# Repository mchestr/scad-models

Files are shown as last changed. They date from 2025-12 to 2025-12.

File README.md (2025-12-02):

# OpenSCAD Models

A collection of parametric 3D models designed in OpenSCAD for 3D printing.

## Projects

| Project | Description |
|---|---|
| [PSU + QuinLED Enclosure](projects/psu-quinled-enclosure/) | Combined enclosure for a 350W PSU and QuinLED-Dig-Quad controller |

## Structure

```
scad-models/
├── projects/           # Individual model projects
│   └── <project-name>/
│       ├── *.scad      # OpenSCAD source files
│       ├── exports/    # Exported STL files
│       └── README.md   # Project documentation
└── README.md
```

## Usage

1. Open any `.scad` file in [OpenSCAD](https://openscad.org/)
2. Use the Customizer panel to adjust parameters
3. Render (F6) and export to STL for printing

## Requirements

- [OpenSCAD](https://openscad.org/) 2019.05 or later (for Customizer support)

## License

See [LICENSE](LICENSE) for details.

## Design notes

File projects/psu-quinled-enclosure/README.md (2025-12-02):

# PSU + QuinLED Enclosure

A combined enclosure for a 350W power supply and QuinLED-Dig-Quad LED controller, designed for LED lighting projects.

## Features

- Side-by-side layout with PSU and QuinLED controller
- Divider wall with U-shaped cable routing slits
- Ventilation slots on sides and honeycomb lid vents
- Sliding lid design (no screws needed)
- Antenna hole for WiFi/Zigbee connectivity
- LED cable slit for wire routing
- Parametric design - all dimensions customizable

## Components

| Component | Dimensions | Mounting |
|---|---|---|
| PSU | 215.9mm x 115mm x 50mm | M4 screws from bottom |
| QuinLED-Dig-Quad | 100mm x 48mm x 25mm | M2.5 standoffs |

## File Structure

| File | Description |
|---|---|
| `config.scad` | Shared parameters and helper modules |
| `body.scad` | Main enclosure body |
| `lid.scad` | Sliding lid with honeycomb vents |
| `grommet.scad` | Strain relief grommet for power cable |
| `assembled.scad` | Combined view of all parts |

## Parts to Print

- `body.scad` - Main enclosure body (240mm x 186mm x 64mm)
- `lid.scad` - Sliding lid, prints rails-up (240mm x 186mm x 4mm)
- `grommet.scad` - Strain relief grommet

## Assembly

1. Print body and lid
2. Mount PSU with M4 screws from bottom (countersunk)
3. Mount QuinLED board on standoffs with M2.5 screws
4. Route power cables through divider U-slits
5. Route LED cables through side slit
6. Install antenna through back hole
7. Insert grommet into power cable hole
8. Slide lid in from right side until it stops

## Customization

Edit `config.scad` to adjust parameters:

- **PSU Dimensions** - Adjust for different power supplies
- **QuinLED Board** - Board dimensions and mounting holes
- **Wire Routing** - Antenna, LED slit, and power hole sizes
- **Ventilation** - Slot dimensions and spacing

## Exports

Pre-exported STL files in `exports/` directory.

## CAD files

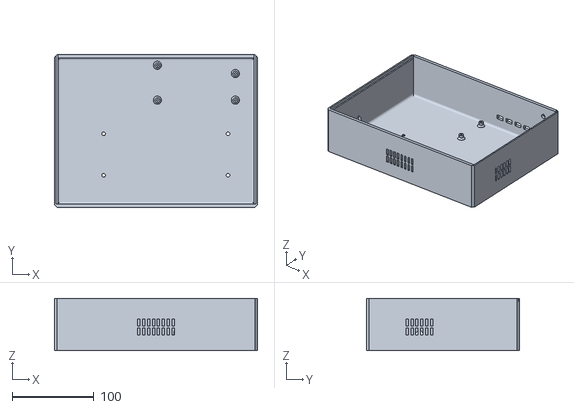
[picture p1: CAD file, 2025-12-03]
projects/psu-quinled-enclosure/exports/body.stl
248.0 x 186.6 x 64.0

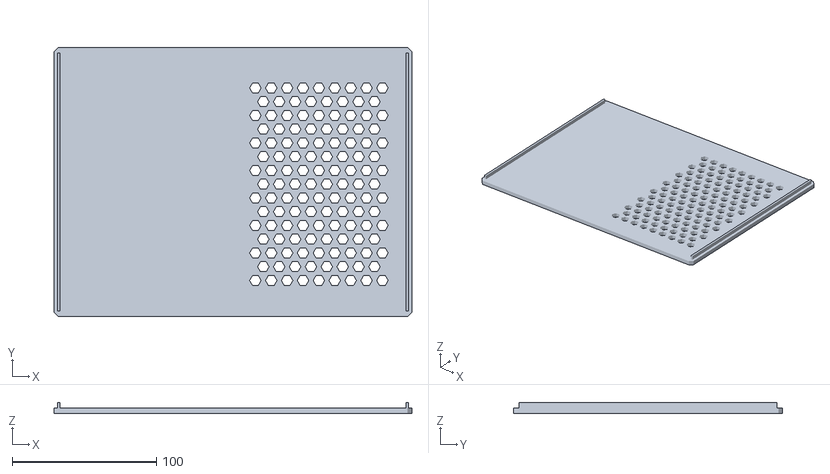
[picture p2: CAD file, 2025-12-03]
projects/psu-quinled-enclosure/exports/lid.stl
248.0 x 186.6 x 7.70

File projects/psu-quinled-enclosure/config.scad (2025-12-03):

// Shared Configuration for PSU + QuinLED Enclosure
// Include this file in other modules to access parameters

/* [Print Compensation] */
// Shrinkage compensation factor (1.0 = none, 1.0135 = ~1.35% for PLA)
// If 150mm prints as 148mm: 150/148 = 1.0135
shrinkage_comp = 1.0135;

/* [PSU Dimensions] */
psu_length = 216;  // 8.5 inches
psu_width = 115;
psu_height = 50;

/* [PSU Mounting Holes] */
psu_hole_spacing_length = 150 * shrinkage_comp;  // Center-to-center distance lengthwise
psu_hole_spacing_width = 50 * shrinkage_comp;    // Center-to-center distance widthwise
psu_screw_dia = 4;  // M4 screws from bottom
psu_screw_head_dia = 8;  // M4 screw head

/* [QuinLED Board] */
quinled_length = 100 * shrinkage_comp;
quinled_width = 48 * shrinkage_comp;
quinled_height = 25;
quinled_hole_edge = 3 * shrinkage_comp;
quinled_hole_offset_back_right = 13 * shrinkage_comp;  // Back-right hole is 13mm from right edge
quinled_hole_dia = 2.5;  // M2.5
quinled_standoff_dia = 6;
quinled_standoff_height = 6;

/* [Enclosure Settings] */
clearance = 3;  // General clearance around components
terminal_clearance = 18;  // Extra space at back for PSU terminal wiring (actual measured offset)
wall = 4;  // Wall thickness
lid_tolerance = 0.3;
chamfer_size = 3;  // Corner chamfer size
internal_fillet_r = 3;  // Internal corner fillet radius for strength

/* [Sliding Lid] */
rail_height = 4;  // Height of the rail/groove
rail_depth = 2;   // How far rail projects into groove
rail_tolerance = 0.3;  // Sliding clearance

/* [Layout] */
gap_between = 3;  // Gap between PSU and QuinLED section
divider_slit_width = 30;  // Slit in divider for power cables
divider_slit_height = 25; // Depth of U-slit from top

/* [Wire Routing] */
antenna_dia = 6;
antenna_offset_from_back = 20;   // Antenna hole distance from back wall
antenna_offset_from_top = 15;    // Antenna hole distance from top
led_slit_width = 80;
led_slit_height = 15;
psu_power_hole_dia = 10;         // PSU AC power cable hole
psu_power_hole_z = 15;           // Height of power cable hole from floor
extra_wire_hole_dia = 10;        // Extra wire routing hole diameter

/* [JST-SM Connectors] */
jst_width = 10;           // Width of JST-SM panel cutout
jst_height = 6;           // Height of JST-SM panel cutout
jst_spacing = 15;         // Spacing between connectors
jst_corner_radius = 1;    // Corner radius for rounded cutouts
jst_count = 4;            // Number of JST connectors

/* [QuinLED Placement] */
quinled_offset_from_back = 20;   // Distance from back wall to QuinLED board

/* [Ventilation] */
slot_width = 3;
slot_length = 20;
slot_spacing = 6;
slot_bridge = 2;      // Bridge between split slots for printability
vent_coverage = 0.8;  // Percentage of lid width covered by honeycomb

/* [Hidden] */
$fn = 60;

// Calculated dimensions
quinled_section_width = quinled_width + clearance * 2;
inner_length = psu_length + clearance * 2 + terminal_clearance;
inner_width = psu_width + clearance * 2 + gap_between + quinled_section_width;
inner_height = psu_height + 10;  // 10mm clearance above PSU for wiring
outer_length = inner_length + wall * 2;
outer_width = inner_width + wall * 2;
outer_height = inner_height + wall;

// Area positions
psu_area_start_x = wall + clearance;
psu_area_start_y = wall + clearance;
psu_area_end_y = psu_area_start_y + psu_width;
quinled_area_start_y = psu_area_end_y + gap_between;
quinled_area_center_y = quinled_area_start_y + quinled_section_width / 2;

// QuinLED board position
quinled_board_x = outer_length - wall - quinled_offset_from_back - quinled_length;
quinled_board_y = quinled_area_start_y + clearance;

// Helper modules
module corner_chamfer(size, height) {
    linear_extrude(height)
        polygon([[0, 0], [size, 0], [0, size]]);
}

module cylinder_fillet(d, fillet_r) {
    rotate_extrude()
        translate([d/2 - fillet_r, 0, 0])
            difference() {
                square([fillet_r + 0.1, fillet_r + 0.1]);
                translate([fillet_r, fillet_r, 0])
                    circle(r=fillet_r);
            }
}

module internal_fillet(length, radius) {
    difference() {
        cube([length, radius, radius]);
        translate([-0.1, radius, radius])
            rotate([0, 90, 0])
                cylinder(r=radius, h=length + 0.2);
    }
}

module standoff(outer_d, inner_d, height, fillet_r=1.5) {
    difference() {
        union() {
            cylinder(d=outer_d, h=height);
            cylinder_fillet(outer_d, fillet_r);
        }
        translate([0, 0, -0.5])
            cylinder(d=inner_d, h=height + 1);
    }
}

// Teardrop hole for horizontal holes (printable without supports)
// Oriented to extrude along X-axis
module teardrop_h(d, len) {
    r = d/2;
    rotate([0, 90, 0]) linear_extrude(len) rotate([0, 0, 90])
    union() {
        circle(r=r);
        polygon([[r*cos(45), r*sin(45)], [0, r*sqrt(2)], [r*cos(135), r*sin(135)]]);
    }
}

// Ventilation slot pattern with bridge for printability
// count: number of slots, spacing: center-to-center distance
module vent_slot_pattern(count, spacing, width, length, bridge, wall_thickness) {
    slot_half = (length - bridge) / 2;
    for (i = [0 : count - 1]) {
        for (z_off = [bridge/2 + slot_half/2, -bridge/2 - slot_half/2])
            translate([i * spacing, 0, z_off])
                cube([width, wall_thickness + 2, slot_half], center=true);
    }
}

// Rounded rectangle cutout (for panel mount connectors)
module rounded_rect_cutout(width, height, radius, depth) {
    hull() {
        for (x = [radius, width - radius])
            for (z = [radius, height - radius])
                translate([x, 0, z]) rotate([-90, 0, 0]) cylinder(r=radius, h=depth);
    }
}

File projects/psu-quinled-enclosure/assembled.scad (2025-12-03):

// Assembled View
// Shows all components in their assembled positions

include <config.scad>
use <body.scad>
use <lid.scad>
use <grommet.scad>

// Grommet dimensions (matching grommet.scad)
grommet_flange_thickness = 2;

// Body
enclosure_body();

// Mockups (PSU, QuinLED)
mockups();

// Lid in assembled position
translate([0, 0, outer_height])
    lid();

// Grommet at PSU power cable hole (front wall)
translate([-grommet_flange_thickness, psu_area_start_y + psu_width/2, wall + 15])
    rotate([0, 90, 0])
        grommet();

// Info
echo("=== ASSEMBLED VIEW ===");
echo("Total dimensions:", outer_length, "x", outer_width, "x", outer_height + wall);
echo("Lid slides in from RIGHT side (Y=max)");

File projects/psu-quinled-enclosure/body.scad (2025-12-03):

// Enclosure Body - Optimized & Cleaned
// Fits original Lid design perfectly
include <config.scad>

// --- Settings ---
show_mockups = false; // Set to false to hide the PSU/QuinLED ghosts

// Push PSU back, but ensure we leave room for the terminals at the back
// We position it so the back of the PSU body leaves exactly 'terminal_clearance' space
psu_x_pos = wall + inner_length - psu_length - terminal_clearance;

module enclosure_body() {
    // PSU center adjusted for 180deg rotation (pushed back by terminal_clearance)
    psu_cx = psu_x_pos + terminal_clearance + psu_length / 2;
    psu_cy = psu_area_start_y + psu_width / 2;
    rail_z = outer_height - rail_height;
    
    union() {
        difference() {
            // Main Shell & Cavity
            cube([outer_length, outer_width, outer_height]);
            translate([wall, wall, wall]) 
                cube([inner_length, inner_width, inner_height + 1]);

            // Lid Rail Grooves (Left & Right walls)
            // Grooves run along Y-axis for front-loading sliding lid
            for (x_pos = [wall - rail_depth, outer_length - wall]) {
                translate([x_pos, wall, rail_z])
                    cube([rail_depth + 0.1, inner_width + wall + 0.1, rail_height + 0.1]);
            }

            // External Corner Chamfers
            cham_h = outer_height + 0.2;
            translate([0, 0, -0.1]) corner_chamfer(chamfer_size, cham_h);
            translate([0, outer_width, -0.1]) rotate([0, 0, -90]) corner_chamfer(chamfer_size, cham_h);
            translate([outer_length, 0, -0.1]) rotate([0, 0, 90]) corner_chamfer(chamfer_size, cham_h);
            translate([outer_length, outer_width, -0.1]) rotate([0, 0, 180]) corner_chamfer(chamfer_size, cham_h);

            // PSU Mounting Holes (Countersunk)
            psu_holes = [
                [psu_cx - psu_hole_spacing_length/2, psu_cy - psu_hole_spacing_width/2],
                [psu_cx - psu_hole_spacing_length/2, psu_cy + psu_hole_spacing_width/2],
                [psu_cx + psu_hole_spacing_length/2, psu_cy - psu_hole_spacing_width/2],
                [psu_cx + psu_hole_spacing_length/2, psu_cy + psu_hole_spacing_width/2]
            ];
            for (p = psu_holes) {
                translate([p[0], p[1], -0.1]) cylinder(d=psu_screw_dia + 0.5, h=wall + 0.2);
                translate([p[0], p[1], -0.1]) cylinder(d1=psu_screw_head_dia + 1, d2=psu_screw_dia + 0.5, h=2.5);
            }

            // Front: Power Cable Hole (Teardrop)
            translate([-1, psu_area_start_y + psu_width/2, wall + psu_power_hole_z])
                teardrop_h(psu_power_hole_dia, wall + 2);

            // Left Side (Front Wall): Ventilation
            translate([outer_length/2 - 3.5 * slot_spacing, wall/2, wall + psu_height/2])
                vent_slot_pattern(8, slot_spacing, slot_width, slot_length, slot_bridge, wall);

            // Back Wall: Ventilation (rotated 90°)
            translate([outer_length - wall/2, psu_area_start_y + psu_width/2 - 2.5 * slot_spacing, wall + psu_height/2])
                rotate([0, 0, 90])
                    vent_slot_pattern(6, slot_spacing, slot_width, slot_length, slot_bridge, wall);

            // Right Side: JST-SM connector holes
            jst_total_width = (jst_count - 1) * jst_spacing + jst_width;
            jst_start_x = quinled_board_x + quinled_length/2 - jst_total_width/2;
            jst_z = wall + quinled_standoff_height + 8;

            for (i = [0 : jst_count - 1]) {
                translate([jst_start_x + i * jst_spacing, outer_width - wall - 1, jst_z])
                    rounded_rect_cutout(jst_width, jst_height, jst_corner_radius, wall + 2);
            }

            // Right Side: Extra wire hole
            extra_hole_x = jst_start_x + jst_total_width + jst_spacing;
            translate([extra_hole_x, outer_width - wall - 1, jst_z + jst_height/2])
                rotate([-90, 0, 0]) cylinder(d=extra_wire_hole_dia, h=wall + 2);

            // Right Side: Antenna (Teardrop)
            translate([outer_length - wall - antenna_offset_from_back, outer_width - wall - 1, outer_height - antenna_offset_from_top])
                rotate([0, 0, 90]) teardrop_h(antenna_dia, wall + 2);
        }

        // --- Additive Parts ---

        // Internal floor-wall fillets for strength and print quality
        // Front wall fillet
        translate([wall, wall, wall])
            internal_fillet(inner_length, internal_fillet_r);
        // Back wall fillet
        translate([wall + inner_length, wall + inner_width, wall])
            rotate([0, 0, 180]) internal_fillet(inner_length, internal_fillet_r);
        // Left wall fillet
        translate([wall, wall + inner_width, wall])
            rotate([0, 0, -90]) internal_fillet(inner_width, internal_fillet_r);
        // Right wall fillet
        translate([wall + inner_length, wall, wall])
            rotate([0, 0, 90]) internal_fillet(inner_width, internal_fillet_r);

        // QuinLED Standoffs (Reinforced) - on right side
        q_x = quinled_board_x;
        q_y = quinled_board_y;
        q_mounts = [
            [q_x + quinled_hole_edge, q_y + quinled_hole_edge],
            [q_x + quinled_length - quinled_hole_edge, q_y + quinled_hole_edge],
            [q_x + quinled_hole_edge, q_y + quinled_width - quinled_hole_edge],
            [q_x + quinled_length - quinled_hole_edge, q_y + quinled_width - quinled_hole_offset_back_right]
        ];
        for (p = q_mounts) translate([p[0], p[1], wall]) {
            standoff(quinled_standoff_dia, quinled_hole_dia, quinled_standoff_height);
            cylinder(d1=quinled_standoff_dia + 4, d2=quinled_standoff_dia, h=2.5); // Reinforced base
        }

        // Lid Stops
        for (x_pos = [wall - rail_depth, outer_length - wall])
            translate([x_pos, wall - 1.5, rail_z]) cube([rail_depth, 1.5, rail_height]);
    }
}
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

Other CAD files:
projects/psu-quinled-enclosure/grommet.scad
projects/psu-quinled-enclosure/lid.scad

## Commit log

2025-12-02 Add PSU + QuinLED enclosure project
    - Combined enclosure for 350W PSU and QuinLED-Dig-Quad controller
    - Parametric OpenSCAD design with Customizer support
    - Side-by-side layout with divider and cable routing
    - Screw-down lid with ventilation and fan cutout
    [psu_quinled_body.stl, psu_quinled_combined.scad]
2025-12-02 Export body and lid STL files separately
    [body.stl, lid.stl, psu_quinled_body.stl]
2025-12-02 Fix PSU mounting holes: 50x150mm spacing, 4mm diameter
    [body.stl, psu_quinled_combined.scad]
2025-12-02 Add chamfered corners to body and lid
    [body.stl, lid.stl, psu_quinled_combined.scad]
2025-12-02 Add corner cutouts to lid lip for screw boss clearance
    [lid.stl, psu_quinled_combined.scad]
2025-12-02 Improve print quality and structural integrity
    - Add fillets to standoffs and corner screw bosses
    - Honeycomb fan grille pattern (replaces crossing bars)
    - Flip lid for print (lip up, no supports needed)
    - Internal fillets where walls meet floor
    - Strain relief collars with zip-tie grooves on cable holes
    - Rubber feet recesses on bottom
    - Rounded corners on LED cable slit
    - Center bridges on vent slots for wall rigidity
    [lid.stl, psu_quinled_combined.scad]
2025-12-02 Add PSU clearance: 15mm terminal space, notched corner bosses
    [lid.stl, psu_quinled_combined.scad]
2025-12-02 Fix PSU-side corner bosses: L-shaped with screw holes preserved
    [lid.stl, psu_quinled_combined.scad]
2025-12-02 Fix PSU clearance: 8mm all sides, bosses don't intrude into PSU area
    [lid.stl, psu_quinled_combined.scad]
2025-12-02 Proper PSU clearance with full 12mm corner bosses
    - Added boss_clearance (14mm) for PSU-side spacing
    - All corners now have structural 12mm x 12mm bosses
    - 2mm gap between corner bosses and PSU footprint
    - PSU area: 215mm x 115mm with proper clearance on all sides
    - Terminal clearance: 15mm at back for wiring
    [lid.stl, psu_quinled_combined.scad]
2025-12-02 Move antenna to right side, align LED slit with QuinLED board
    [psu_quinled_combined.scad]
2025-12-02 Move antenna hole towards back corner, clear of LED slit
    [psu_quinled_combined.scad]
2025-12-02 Move antenna hole higher, remove strain relief collars for printability
    [psu_quinled_combined.scad]
2025-12-02 Fix screw holes in bosses to not cut through floor
    [psu_quinled_combined.scad]
2025-12-02 Simplify corner bosses, screw hole starts 1mm up for solid base
    [body.stl, psu_quinled_combined.scad]
2025-12-02 Remove rubber feet recesses
    [body.stl, psu_quinled_combined.scad]
2025-12-02 Reduce corner boss size to 10mm to fit 256mm print bed
    [body.stl, lid.stl, psu_quinled_combined.scad]
2025-12-02 Switch to sliding lid design
    - Remove corner screw bosses for simpler construction
    - Add rail/groove system for lid attachment
    - Lid slides in from right side (Y=max)
    - End stops prevent over-insertion
    - Reduced overall dimensions to 246.9mm x 194mm
    - Better fit for 256mm print bed
    [body.stl, lid.stl, psu_quinled_combined.scad]
2025-12-02 Fix sliding lid design
    - Extend grooves to right edge for lid entry
    - Rails now project downward from lid plate
    - Trim lid plate to clear walls when sliding
    - Left wall acts as natural end-stop
    - Updated print orientation for rails-up
    [body.stl, lid.stl, psu_quinled_combined.scad]
2025-12-02 Fix fan vent position on lid
    - Move fan vent to 75mm from left edge of PSU
    - Matches actual fan location (38mm from right edge)
    [body.stl, lid.stl, psu_quinled_combined.scad]
2025-12-02 Fix lid plate dimensions and vent positions
    - Lid plate now covers full outer dimensions
    - QuinLED vents reduced to 5x5 grid with 10mm spacing
    - Vents no longer cut off at edges
    - Assembled and standalone lid now match
    [lid.stl, psu_quinled_combined.scad]
2025-12-02 Mirror fan vent position on lid
    - Moved from front-right to back-left of PSU area
    - fan_from_front: 48 -> 168mm
    - fan_from_left: 75 -> 40mm
    [lid.stl, psu_quinled_combined.scad]
2025-12-02 Move fan grille to bottom right, remove orientation labels
    - Fan position: 48mm from front, 75mm from left edge of PSU
    - Removed debug orientation_labels module
    - Removed 'labeled' part option
    [lid.stl, psu_quinled_combined.scad]
2025-12-02 Fix fan grille position to bottom right
    - Changed from fan_from_front to fan_from_back calculation
    - fan_from_back=48mm, fan_from_left=40mm
    - This places fan at high X (back/right of view) and low Y (PSU wall/bottom of view)
    [lid.stl, psu_quinled_combined.scad]
2025-12-02 Fix fan X position to 75mm from front of PSU
    [lid.stl, psu_quinled_combined.scad]
2025-12-02 Flip fan position to opposite corners
    - X: 75mm from back of PSU
    - Y: 40mm from right edge of PSU
    [lid.stl, psu_quinled_combined.scad]
2025-12-02 Simplify lid with single honeycomb vent pattern
    - Replace separate fan grille and QuinLED vents with unified honeycomb
    - Honeycomb spans 80% of width, 70% of length, centered
    - Configurable via vent_coverage parameter
    - Removed fan position parameters
    [lid.stl, psu_quinled_combined.scad]
2025-12-02 Reduce honeycomb length to 50% of lid
    [lid.stl, psu_quinled_combined.scad]
2025-12-02 Position honeycomb near back, 100mm length
    [lid.stl, psu_quinled_combined.scad]
2025-12-02 Increase wall thickness for stronger lid grooves
    - Wall: 3mm -> 5mm
    - Now leaves 2.5mm of solid wall after groove (was only 0.5mm)
    - New dimensions: 250.9mm x 198mm x 65mm (still fits 256mm bed)
    [body.stl, lid.stl, psu_quinled_combined.scad]
2025-12-02 Reduce dimensions for smaller print bed
    - clearance: 5mm -> 3mm
    - terminal_clearance: 15mm -> 10mm
    - wall: 5mm -> 4mm (with rail_depth 2mm, leaves 2mm wall)
    - gap_between: 5mm -> 3mm
    - New dimensions: 239.9mm x 186mm x 61mm (was 250.9 x 198 x 65)
    [body.stl, lid.stl, psu_quinled_combined.scad]
2025-12-02 Add strain relief grommet
    - Snap-fit design for 8mm power cable hole
    - Fits 5mm cable with grip ridges
    - Split slot allows cable insertion without threading
    - Parametric - adjust hole_dia and cable_dia as needed
    - 14mm total length (2mm flange + 4mm wall + 8mm grip)
    [grommet.scad, grommet.stl]
2025-12-02 Update grommet and hole for 7mm cable
    - Grommet cable_dia: 5mm -> 7mm
    - Hole diameter: 8mm -> 10mm (gives 1.5mm grommet walls)
    [body.stl, grommet.scad, grommet.stl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]
2025-12-02 Fix printability issues and documentation
    - Increase lid end stop thickness from 0.5mm to 1.5mm for reliable printing
    - Increase rail tolerance from 0.2mm to 0.3mm for smoother sliding fit
    - Fix README: M3 → M4 screws, correct sliding lid assembly instruction
    [body.stl, lid.stl, psu_quinled_combined.scad]
2025-12-02 Refactor into modular SCAD files
    - Split psu_quinled_combined.scad into separate files:
    - config.scad: shared parameters and helper modules
    - body.scad: enclosure body
    - lid.scad: sliding lid
    - assembled.scad: combined view
    - Increase PSU clearance to 10mm for wiring
    - Update README with new file structure
    [assembled.scad, body.scad, body.stl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]
2025-12-02 Fix internal fillet geometry extending outside box
    Remove incorrectly oriented internal fillets that were causing
    geometry to extend far outside the enclosure bounds.
    [assembled.scad, body.scad, body.stl]
2025-12-03 Improve code quality and add STL exports
    - Simplify lid rail logic (remove redundant confusing code)
    - Move magic numbers to config.scad for maintainability
    - Add internal floor-wall fillets for strength and print quality
    - Extract reusable modules: teardrop_h, vent_slot_pattern, rounded_rect_cutout
    - Add STL exports for body, lid, and grommet
    [assembled.scad, body.scad, body.stl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]
2025-12-03 Move STL exports to exports directory
    [body.stl, grommet.stl, lid.stl]
2025-12-03 Remove mock parts from body STL export
    Set show_mockups=false so the exported STL only contains
    the printable enclosure body without PSU/QuinLED visualization.
    [body.scad, body.stl]
2025-12-03 Fix antenna hole rotation direction
    The teardrop was extruding in -Y direction (into enclosure) instead of +Y direction (through the wall). Changed rotation from -90 to +90 degrees.
    [body.scad, body.stl]
